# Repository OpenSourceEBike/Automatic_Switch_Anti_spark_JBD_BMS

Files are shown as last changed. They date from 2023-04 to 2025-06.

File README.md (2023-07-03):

# Automatic switch anti-spark for JBD BMS

**What:** a small DIY board that automatically switches on the [popular JBD BMS](https://jiabaidabms.com/), effectively switching on the EBike/EScooter, when there is motion / vibration.<br>
A timeout of 2 minutes, if no motion is detected, will automatically switch off. Also, a wireless communication accepts a command (for instance, sent from a display) to switch off.

Avoids the need to install a mechanical switch and also adds the safe timeout that automatically switches off the EBike/EScooter.

On the next picture, the DIY board:<br>
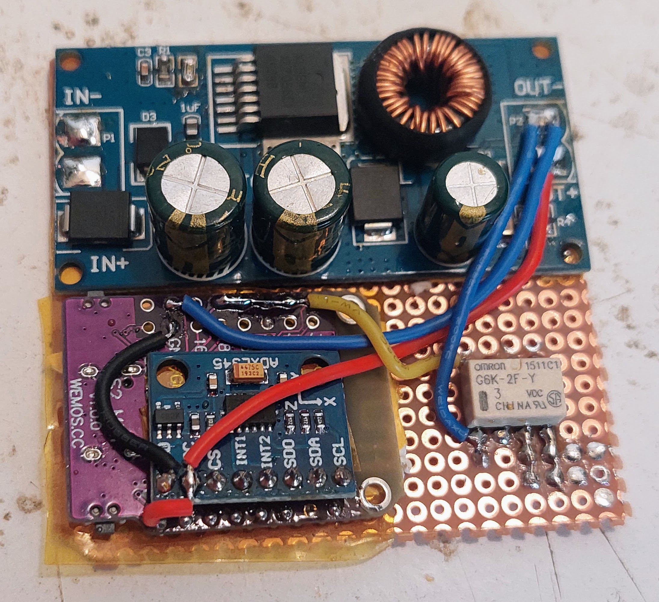
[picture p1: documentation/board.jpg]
[](documentation/board.jpg)

## Features ##
* **Switches on the EBike/EScooter by detection motion:** JBD BMS switches on when there is motion of the EBike/EScooter.
* **Automatic switches off the EBike/EScooter:** JBD BMS switches off after 2 minutes, when there is no more motion.
* **[Ultra low power](https://learn.adafruit.com/deep-sleep-with-circuitpython/power-consumption):** espected to use only 0.007 watts when JBD BMS is switched off (will take 8 years to discharge a 500Wh battery).
* **Cheap and easy to DIY:** costs 10€ in materials and needs only soldering 10 wires.
* **Wireless communication with other boards:** an EBike/EScooter display board can send a command by wireless, to switch off immediatly the JBD BMS.

## How to build it ##

You will need to buy (I bought all the components from Aliexpress):
- DC-DC step down converter (3.3V version)<br>
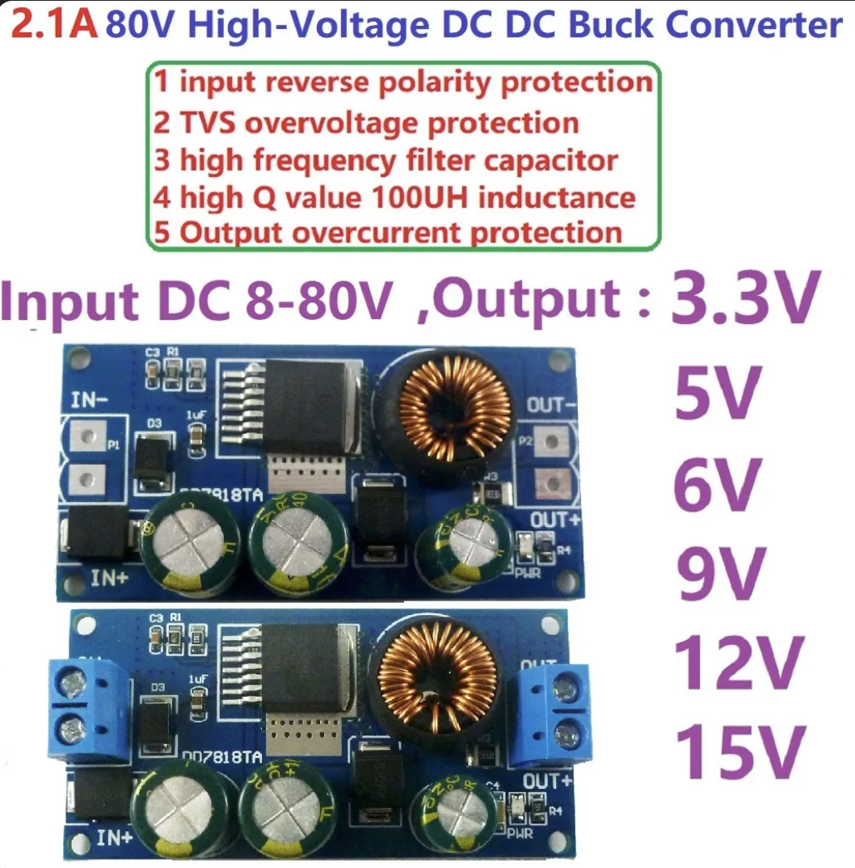
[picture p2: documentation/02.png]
[](documentation/01.png)

- ESP32-S2 Lolin S2 Mini board<br>
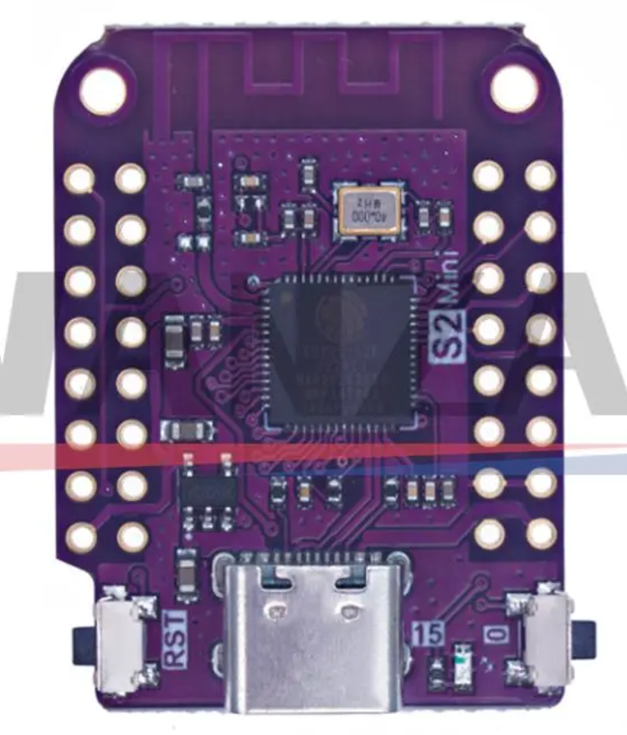
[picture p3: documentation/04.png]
[](documentation/01.png)

- ADXL345 module board<br>
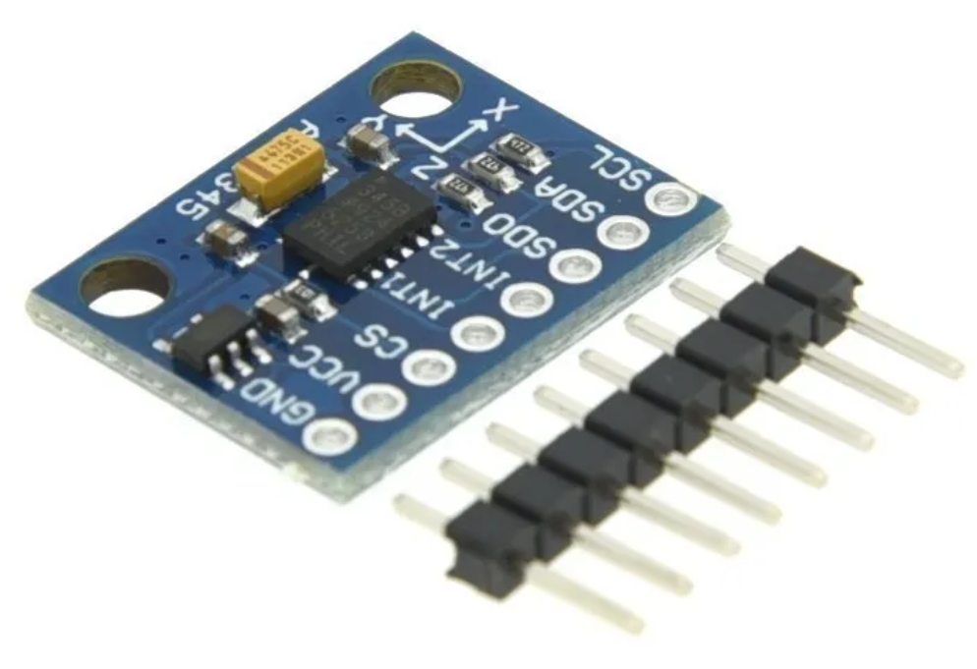
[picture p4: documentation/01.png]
[](documentation/01.png)

- Relay (small signal version, I used Omron G6KU-2F-Y DC3) <br>
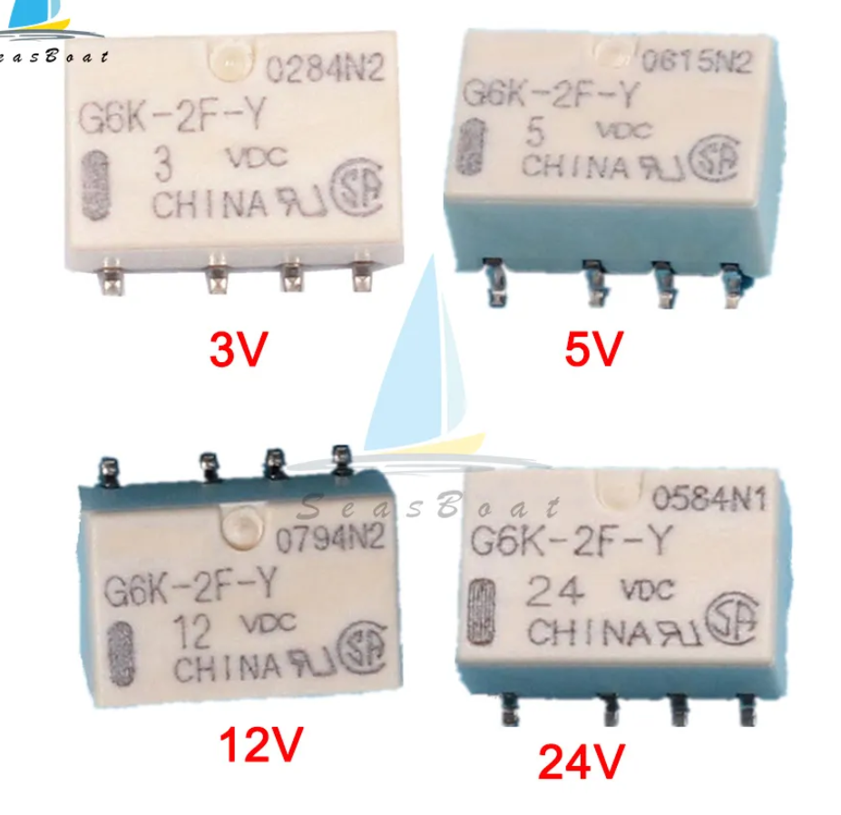
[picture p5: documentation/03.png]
[](documentation/01.png)

### 1. Install CircuitPyhton ###

- Download the [CircuitPyhton binary](https://circuitpython.org/) to your board.<br>

- Connect the ESP32-S2 board in bootloader mode to your PC with a USB-C cable. On Linux I use this command to flash the CircuitPython:<br>

```esptool.py write_flash 0 adafruit-circuitpython-lolin_s2_mini-en_US-8.1.0-beta.1.bin```

- Follow the CircuitPython guides to make sure your board is working, like make some print("hello world") code.

### 2. Install the firmware ###

Connect the ESP32-S2 board to your PC using a USB-C cable. A USB flash disk should apear. Copy all the files and folders inside firmware folder, to the USB flash disk. Unmount the USB flash disk from your PC, remove the USB-C cable. Next time you power up the ESP32-S2 board, the firmware will run, like when connecting again the USB-C cable. See the CircuitPyhton basic tutorial if you have questions.

### 3. Understand the schematic ###

[<img src=hardware/schematic.png width=800>](hardware/schematic.png)

The DC-DC step-down converter, converts the battery voltage to 3.3V. The 3.3V will power the ESP32-S2 board and the ADXL345 module board.

This means the ESP32-S2 will always be running, althought in deep sleep mode, ultra low power, while waiting for the motion pin signal change, that is the output of ADXL345 module.

The ADXL345 module is powered also by the 3.3V and is ultra low power. With motion, the ADXL345 INT1 pin will change.

The relay signal from the ESP32-S2, will have a 3.3V volts to switch on the relay and 0V to switch off the relay (not that 5 connections to the ESP32-S2 are needed, otherwise the 3.3V signal to relay will not be enough to turn it on, as the relay coil may use a good amount of current that can only be provided by the sum of a few ESP32-S2 pins).
The relay open switch pin will be connected to the JBD BMS switch pins.

### 4. Build the board ###

Following the schematic, build the board as the following images.

I did solder the ADXL345 board on the back of the ESP32-S2 board. I used kapton tape to make sure I isolated the back of both boards from touch electronically each other. I also used dual face tape.

I used 6 header pins to solder the pins directly, and avoid the need to wires wires. Still, 2 wires are needed: 3.3V (VCC) and GND (black wire):<br>
[<img src=documentation/old_prototypes/board_01.jpg width=400>](documentation/old_prototypes/board_01.jpg)

[<img src=documentation/old_prototypes/board_02.jpg width=400>](documentation/old_prototypes/board_02.jpg)

Top of the ESP32-S2 board:<br>
[<img src=documentation/old_prototypes/board_03.jpg width=400>](documentation/old_prototypes/board_03.jpg)

Top save the most power possible, I removed the little resistor near the LED and this way there are no energy used by the LED. I also removed the 5 pin little integrated circuit, that is 5V -> 3.3V voltage regulator - note that once you remove it, the board will only work when you provid the 3.3V externally, it will not work any more from the USB-C:<br>
[<img src=documentation/old_prototypes/board_04.jpg width=400>](documentation/old_prototypes/board_04.jpg)

Wire the 3.3V and GND from the DC-DC converter to the ESP32-S2 board. Also wire the relay to the ESP32-S2 pins:
[<img src=documentation/board.jpg width=400>](documentation/board.jpg)

To test if everything is working, measure the voltage with the multimeter between the GND and the 3.3V on the ESP32-S2 board - it must be near 3.3 volts. Then measure between the GND and the relay switch wire - should be near 3.3 volts when the ESP32-S2 board detects motion, but after the timeout, it will be 0V.

NOTE: you can use the JBD BMS app to see the switch state. You will need to enable the switch feature on the app, otherwise it will never switch on.

Finally, use some good tape to cover all the board.

## Understand the firmware (optional) ##

The main firmware is on the main.py file. espnow_comms.py file has the code to received by wireless (for instance, sent by a display) a command to turn off the BMS.

The lib folder has the needed Pyhton libraries, like the adafruit_adxl34x that communicates with the ADXL345 module.

The main firmware:

[<img src=documentation/firmware.png width=900>](documentation/firmware.png)

* Starts by turn the relay switch pins to high state / 3.3 volts, as needed to switch on the relay, that in turn will switch the BMS.
* Initialize the ADXL345 and enable the motion detection. The ADXL345 will change the INT1 pin when it detects motion.
* A PinAlarm is created, this will wakeup the ESP32-S2 everytime the ADXL345 INT1 pin changes.
* The code inside the while True will run continuously until the timeout happens (no motion detected during timeout_minutes_to_disable_relay minutes - 2 minutes) or the wireless command to switch off the relay is received.
* Next code switches off the BMS by turning the relay switch pins to logic 0 / 0 volts.
* Finally, ESP32-S2 enters in deep sleep mode (ultra low power), keeping the relay switch pins in the state to keep the BMS switched off. The motion alarm will be active meaning the ESP32-S2 will then wake up when detection motion, and the firmware will run again starting from the begin.

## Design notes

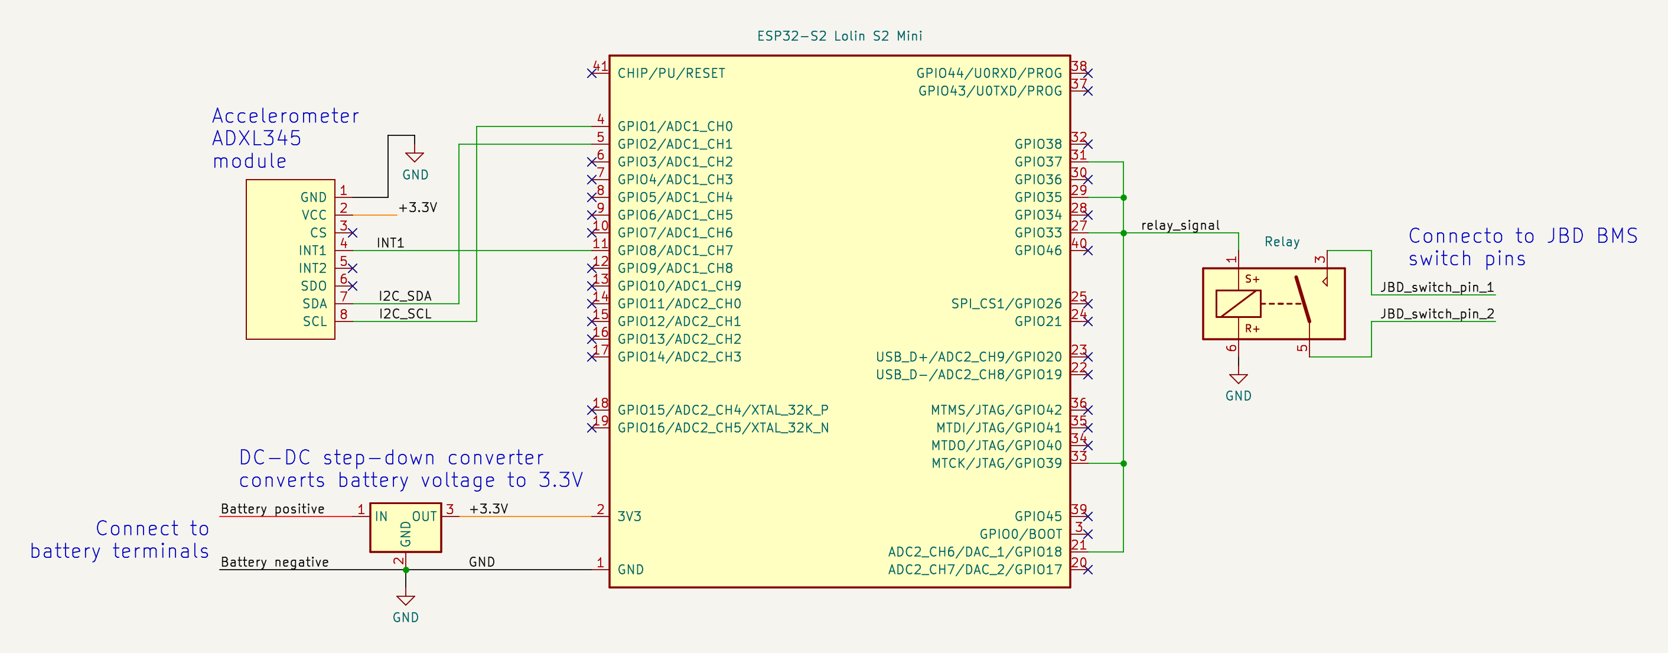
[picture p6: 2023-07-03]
hardware/schematic.png

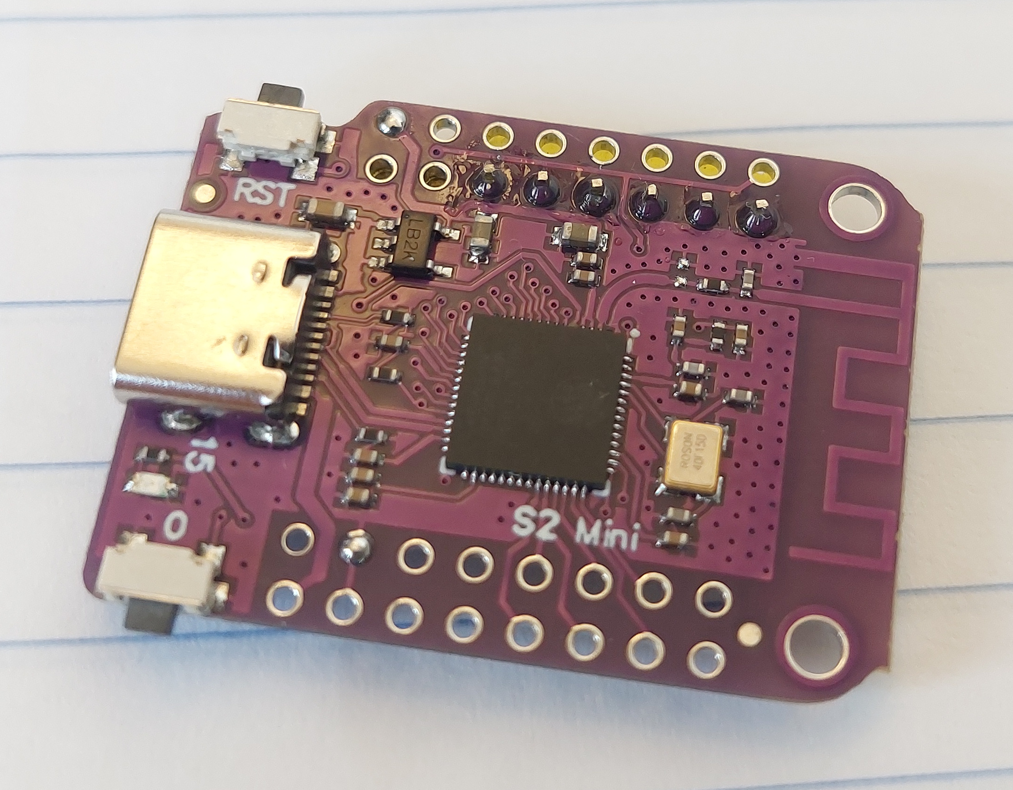
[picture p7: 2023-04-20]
documentation/board_03.jpg

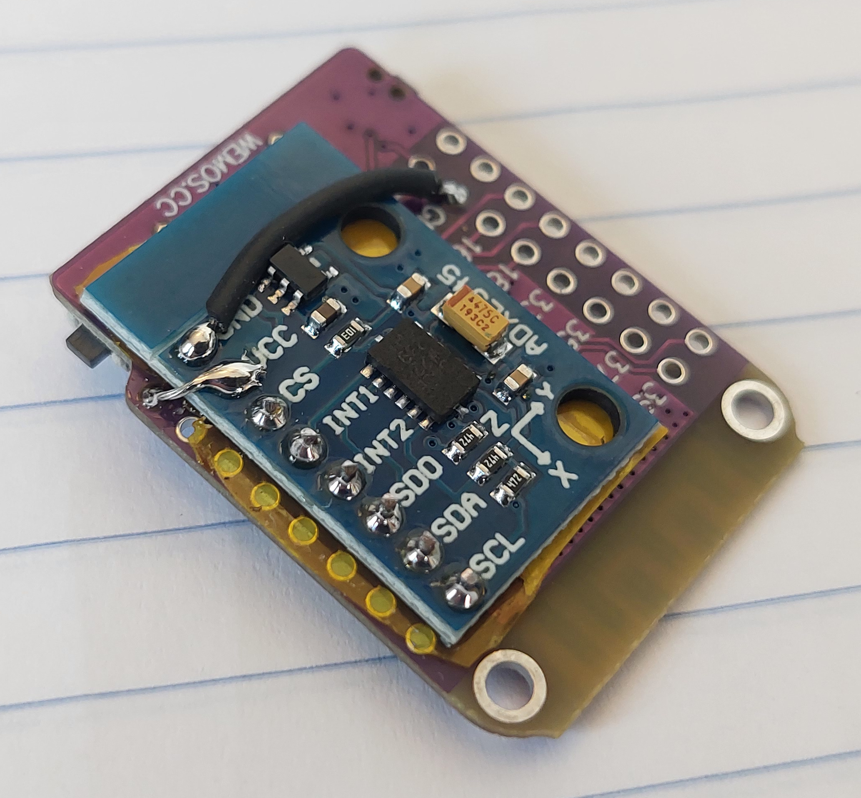
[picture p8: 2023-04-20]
documentation/board_01.jpg

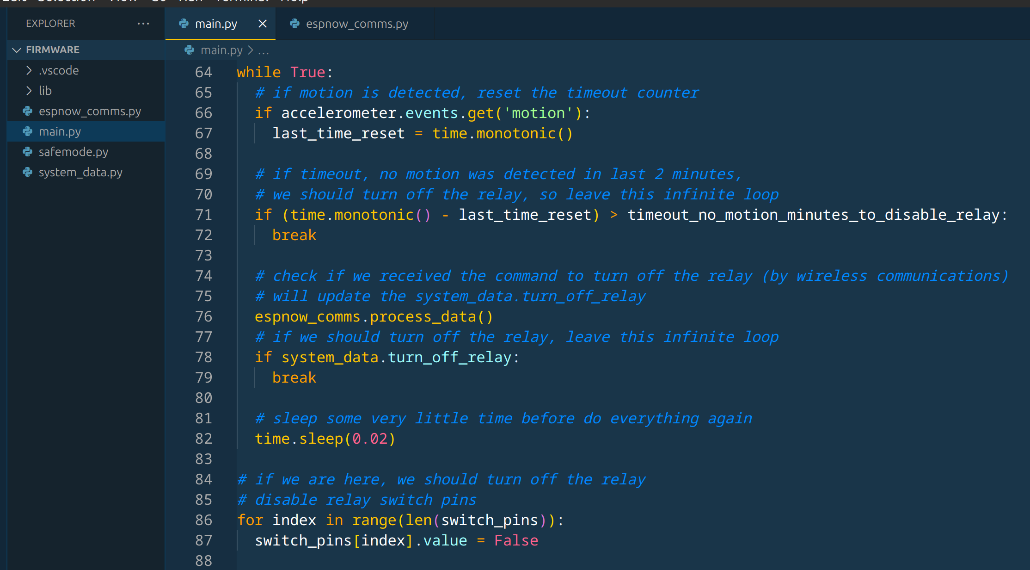
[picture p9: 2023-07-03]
documentation/firmware-1.png

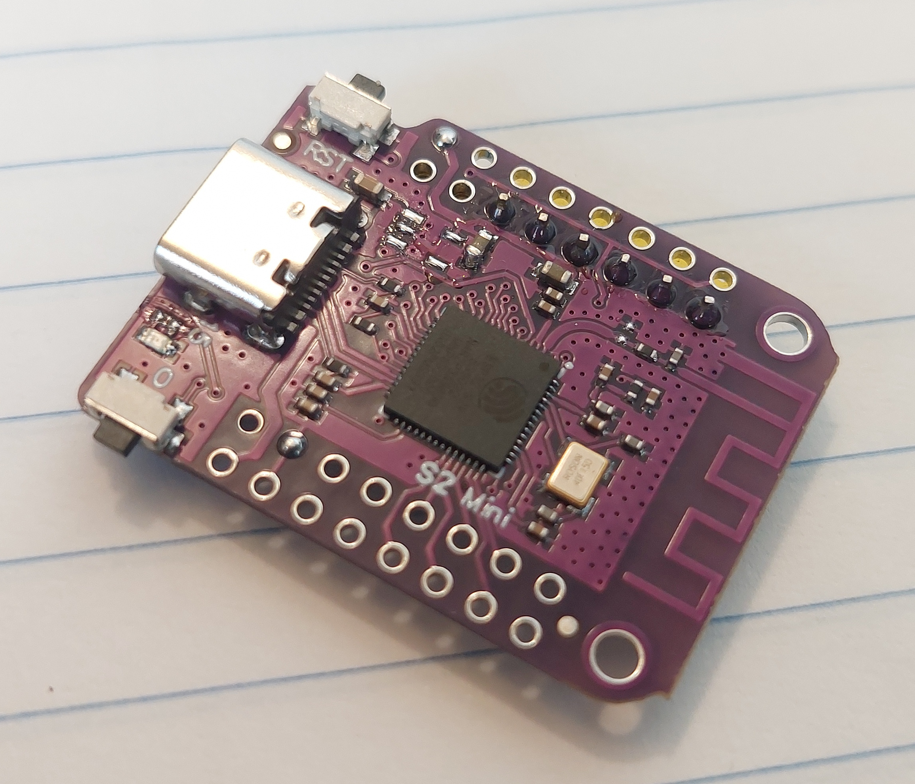
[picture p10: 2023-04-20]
documentation/board_04.jpg

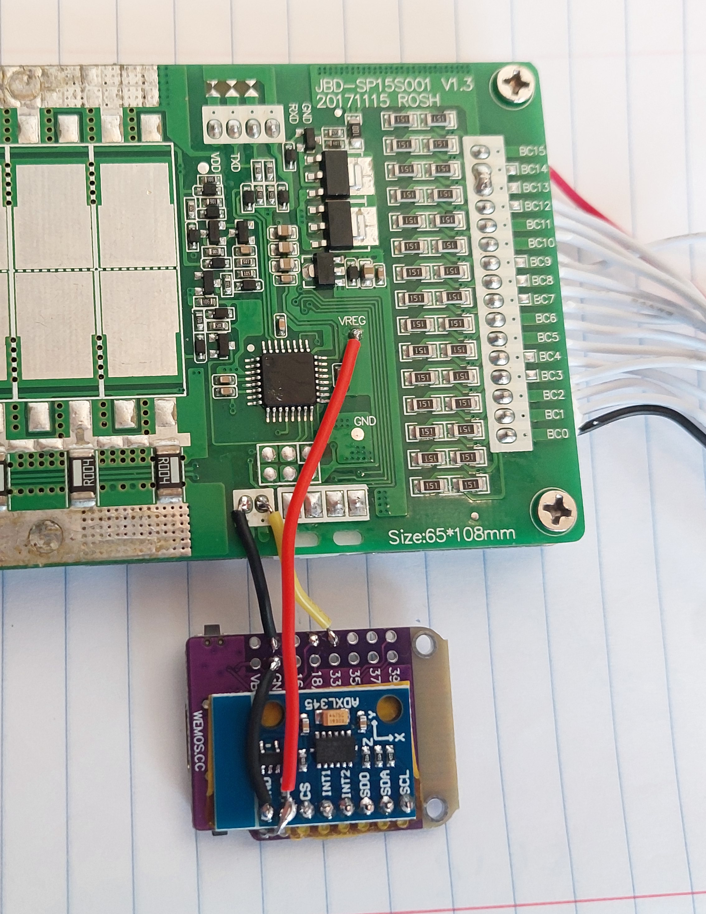
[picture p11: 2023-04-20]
documentation/board_05.jpg

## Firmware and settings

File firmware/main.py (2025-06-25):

import board
import digitalio

import supervisor
supervisor.runtime.autoreload = False

# enable the IO pins to control the switch
# needs a few pins as the relay uses some good amount of current
switch_pins_numbers = [board.IO18, board.IO33, board.IO35, board.IO37, board.IO39]
switch_pins = [0] * len(switch_pins_numbers)

# configure the pins as outputs and enable
for index, switch_pin_number in enumerate(switch_pins_numbers):
  switch_pins[index] = digitalio.DigitalInOut(switch_pin_number)
  switch_pins[index].direction = digitalio.Direction.OUTPUT
  switch_pins[index].value = True

import busio
import adafruit_adxl34x
import alarm
import time
import gc
import wifi
import espnow
import espnow_comms as _ESPNowComms
import system_data as _SystemData

################################################################
# CONFIGURATIONS

timeout_no_motion_minutes_to_disable_relay = 5 # 5 minutes seems a good value

seconds_to_wait_before_movement_detection = 20 # 20 seconds seems a good value

my_mac_address = [0x68, 0xb6, 0xb3, 0x01, 0xf7, 0xf1]

debug_enable = True

################################################################

timeout_no_motion_minutes_to_disable_relay *= 60 # need to multiply by 60 seconds

if debug_enable:
  print("Starting the DIY Automatic Anti Spark Switch")

# if we are here, is because
# the system just wake up from deep sleep,
# due to motion detection

system_data = _SystemData.SystemData()

# set mac address
# this is also need to start ESPNow
wifi.radio.enabled = True
wifi.radio.mac_address = bytearray(my_mac_address)
wifi.radio.start_ap(ssid="NO_SSID", channel=1)
wifi.radio.stop_ap()

_espnow = espnow.ESPNow()
espnow_comms = _ESPNowComms.ESPNowComms(_espnow, system_data)

# pins used by the ADXL345
scl_pin = board.IO1
sda_pin = board.IO2
int1_pin = board.IO8

# init the ADXL345
i2c = busio.I2C(scl_pin, sda_pin)
accelerometer = adafruit_adxl34x.ADXL345(i2c)
accelerometer.enable_motion_detection(threshold = 16) # 16 seems to be the min value possible
accelerometer.events.get('motion') # this will clear the interrupt

last_time_motion_detected = time.monotonic()

if debug_enable:
  motion_counter = 0
  previous_display_communication_counter = 0
  timeout_counter_previous = 0

while True:
  
  # process any data received by ESPNow
  espnow_comms.process_data()
  if debug_enable:
    if system_data.display_communication_counter != previous_display_communication_counter:
      previous_display_communication_counter = system_data.display_communication_counter

  # save time value when motion is detected 
  if accelerometer.events.get('motion'):
    last_time_motion_detected = time.monotonic()
    
    if debug_enable:
      motion_counter += 1
      print(f"Motion counter: {motion_counter}")

  # if we should turn off the relay, leave this infinite loop
  if system_data.turn_off_relay:
    if debug_enable:
      print("Turn off relay command")
      
    break

  # if timeout, leave this infinite loop
  timeout_counter = int(time.monotonic() - last_time_motion_detected)
  if timeout_counter > timeout_no_motion_minutes_to_disable_relay:
    break
  
  if debug_enable:
    if timeout_counter != timeout_counter_previous:
      timeout_counter_previous = timeout_counter
      print(f"Timeout remaining seconds: {timeout_no_motion_minutes_to_disable_relay - timeout_counter}")
  
  # do memory clean
  gc.collect()

  # sleep some very little time
  time.sleep(0.02)


if debug_enable:
  print(f"Prepare to enter in sleep mode - delay of {seconds_to_wait_before_movement_detection} seconds")

# if we are here, we should turn off the relay
# disable relay switch pins
for index in range(len(switch_pins)):
  switch_pins[index].value = False

# wait some time before next movement detection
time.sleep(seconds_to_wait_before_movement_detection)

# pin change alarm, will be active when motion is detected by the ADXL345
pin_alarm_motion_detection = alarm.pin.PinAlarm(int1_pin, value = True)

accelerometer.events.get('motion') # this will clear the interrupt

if debug_enable:
  print("Enter in sleep mode")

alarm.exit_and_deep_sleep_until_alarms(pin_alarm_motion_detection, preserve_dios = switch_pins)
# Does not return. Exits, and restarts after the deep sleep time.

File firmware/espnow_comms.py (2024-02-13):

class ESPNowComms(object):
    def __init__(self, espnow, system_data):
        self._espnow = espnow
        self._packets = []
        self._system_data = system_data
        self.power_switch_id = 4 # power switch ESPNow messages ID
        
    def process_data(self):    
        data = None
        try:
            # read a package and discard others available
            while self._espnow:
                rx_data = self._espnow.read()
                if rx_data is None:
                    break
                else:
                    data = rx_data

            # process the package, if available
            if data is not None:
                data = [n for n in data.msg.split()]
                # only process packages for us
                if int(data[0]) == self.power_switch_id:
                    self._system_data.display_communication_counter = int(data[1])
                    self._system_data.turn_off_relay = True if int(data[2]) != 0 else False

        except Exception as ex:
            print(ex)
            pass

    def send_data(self):
        pass

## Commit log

2023-04-19 Added schematic and README
    [schematic.kicad_sch]
2023-04-20 Updated the schematic based on latest firmware. Firmware detects correclty the movement and deep sleeps
    [schematic.kicad_sch]
2023-04-20 Firmware seems to work as expected, the final version. Updated schematic.png
2023-04-20 Corrected switch pin schematic and firmware. Added pictures of the built unit
    [schematic.kicad_sch]
2023-04-20 Corrected issue on firmware
    [main.py]
2023-06-01 Added buzzer bip to startup and to shutdown
    [main.py]
2023-06-01 Added buzzer bips. Added wireless communication with the display, to turn of the switch with display remote power button long press
    [main.py]
2023-07-03 Added custom MAC address. Now communications do not reset the timeout, only motion detection
    [espnow_comms.py, main.py]
2023-07-03 Updated the shcematic and documentation based on latest board I built
    [schematic.kicad_sch]
2024-02-13 Solved an issue where no data were received by ESPNow. Updated the CircuitPython 9.0.0-beta.0
    [espnow_comms.py, main.py]
